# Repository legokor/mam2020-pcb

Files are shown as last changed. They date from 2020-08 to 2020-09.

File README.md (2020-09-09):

## Pinout

### LoRa
| Pin | ESP GPIO |
| --- | --- |
| MISO (2) | 19 |
| MOSI (3) | 23 |
| CLK (4) | 18 |
| CS (5)| 5 |
| RST (6)| 22 |
| DI0 (14) | 21 |

### Motors
| Pin | ESP GPIO |
| --- | --- |
| MOTOR_1_STEP | 27 |
| MOTOR_1_DIR | 14 |
| MOTOR_2_STEP | 12 |
| MOTOR_2_DIR | 17 |
| MOTOR_MODE_0 | 16 |
| MOTOR_MODE_1 | 4 |
| MOTOR_MODE_2 | 0 |

### ADC
| Pin | ESP GPIO |
| --- | --- |
| BATTERY | 34 |

### Servos
| Pin | ESP GPIO |
| --- | --- |
| SERVO_1 | 25 |
| SERVO_2 | 26 |

### Leds
| Pin | ESP GPIO |
| --- | --- |
| LED_1 | 35 |
| LED_2 | 32 |
| LED_3 | 33 |

### Connector

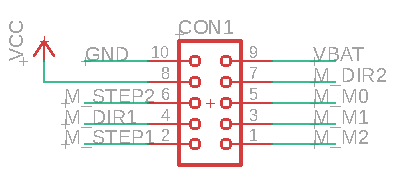
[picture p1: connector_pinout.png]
N|Solid


## Parts list

| Name | Link |
| --- | --- |
| ESP32 | [Pinout](https://www.rpibolt.hu/img/15922/RPI-WS16611_altpic_4/RPI-WS16611_altpic_4.jpg?time=1572739065) |
| DRV8825 | [Datasheet](https://www.pololu.com/product/2133/pictures) |
| HW-613 (DC-DC down) | [Datasheet](https://www.hestore.hu/prod_getfile.php?id=11935) |
| MT3608 (DC-DC up) | [Hestore](https://www.hestore.hu/prod_10038537.html) |
| Stepper motor ( 28BYJ ) | [Datasheet](https://www.hestore.hu/prod_getfile.php?id=8209) |
| RFM95W-868-S2 ( LoRa ) | [Datasheet](https://www.hoperf.com/data/upload/portal/20190301/RFM95_96_97_98W.pdf) |

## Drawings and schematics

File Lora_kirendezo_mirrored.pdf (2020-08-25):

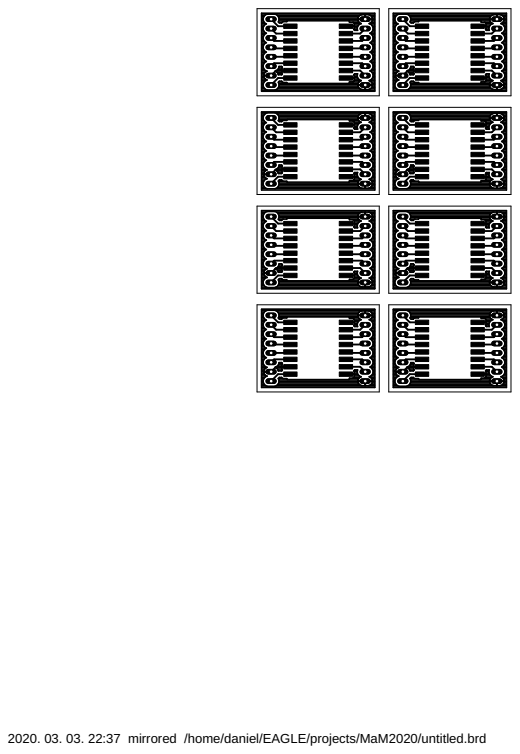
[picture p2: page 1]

2020. 03. 03. 22:37 mirrored /home/daniel/EAGLE/projects/MaM2020/untitled.brd

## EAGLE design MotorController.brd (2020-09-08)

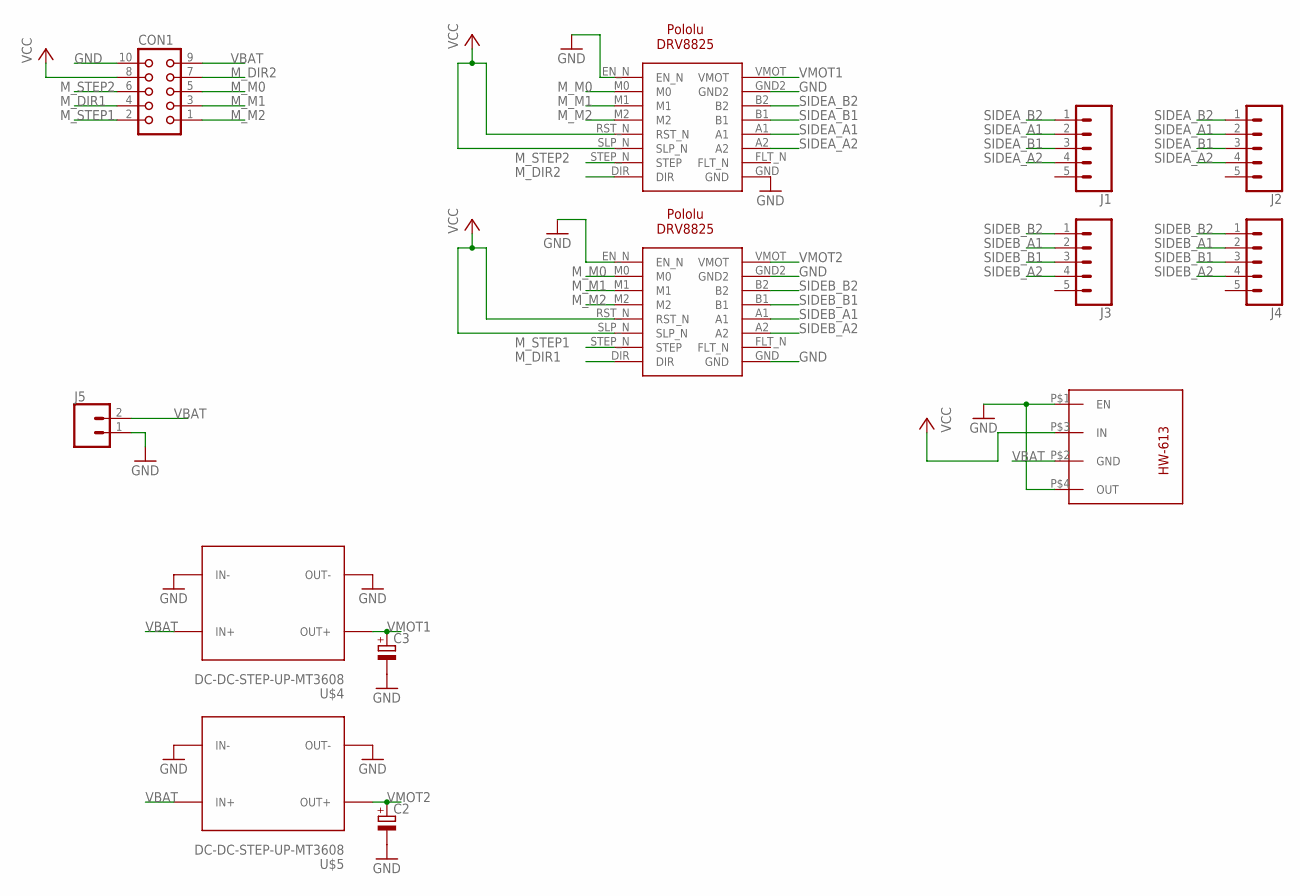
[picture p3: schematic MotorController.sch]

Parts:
C2, C3: CPOL-EUE3.5-10; E3,5-10
CON1: CON10
J1, J2, J3, J4: CONN_05; 1X05
J5: CONN_025MM; SCREWTERMINAL-5MM-2
U$1, U$2: POLOLU-DRV8825
U$4, U$5: DC-DC-STEP-UP-MT3608
U$6: HW-613

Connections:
GND: C2.-, C3.-, CON1.10, J5.1, U$1.EN_N, U$1.GND, U$1.GND2, U$2.EN_N, U$2.GND, U$2.GND2, U$4.IN-, U$4.OUT-, U$5.IN-, U$5.OUT-, U$6.P$1 (EN), U$6.P$4 (OUT)
M_DIR1: CON1.4, U$2.DIR
M_DIR2: CON1.7, U$1.DIR
M_M0: CON1.5, U$1.M0, U$2.M0
M_M1: CON1.3, U$1.M1, U$2.M1
M_M2: CON1.1, U$1.M2, U$2.M2
M_STEP1: CON1.2, U$2.STEP_N (STEP)
M_STEP2: CON1.6, U$1.STEP_N (STEP)
SIDEA_A1: J1.2, J2.2, U$1.A1
SIDEA_A2: J1.4, J2.4, U$1.A2
SIDEA_B1: J1.3, J2.3, U$1.B1
SIDEA_B2: J1.1, J2.1, U$1.B2
SIDEB_A1: J3.2, J4.2, U$2.A1
SIDEB_A2: J3.4, J4.4, U$2.A2
SIDEB_B1: J3.3, J4.3, U$2.B1
SIDEB_B2: J3.1, J4.1, U$2.B2
VBAT: CON1.9, J5.2, U$4.IN+, U$5.IN+, U$6.P$2 (GND)
VCC: CON1.8, U$1.RST_N, U$1.SLP_N, U$2.RST_N, U$2.SLP_N, U$6.P$3 (IN)
VMOT1: C3.+, U$1.VMOT, U$4.OUT+
VMOT2: C2.+, U$2.VMOT, U$5.OUT+

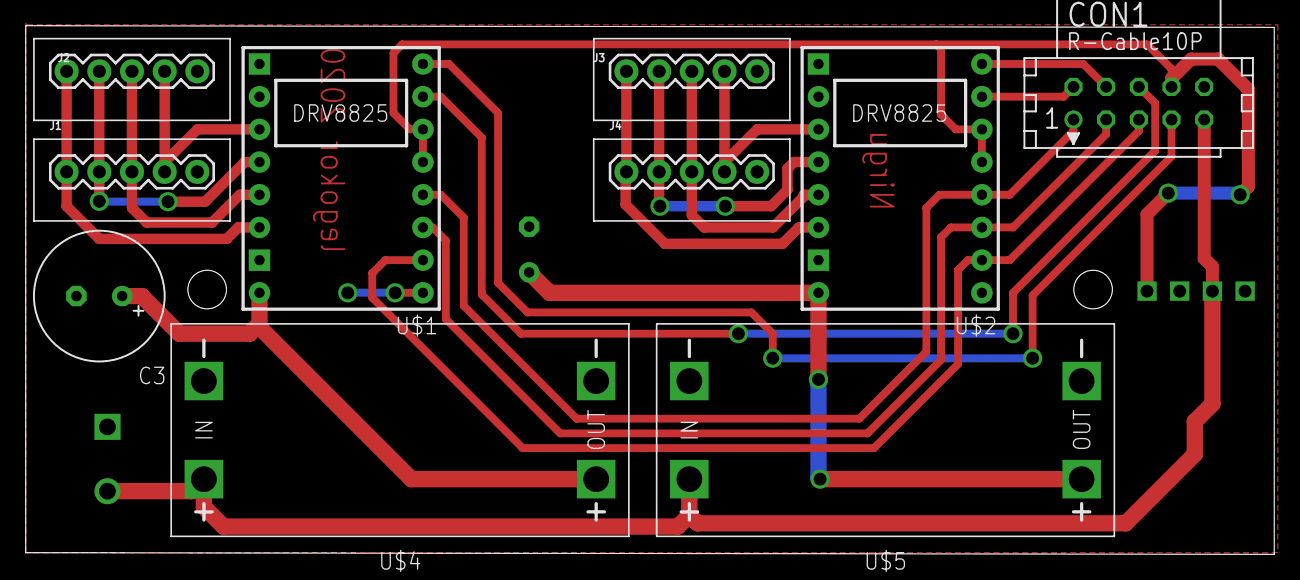
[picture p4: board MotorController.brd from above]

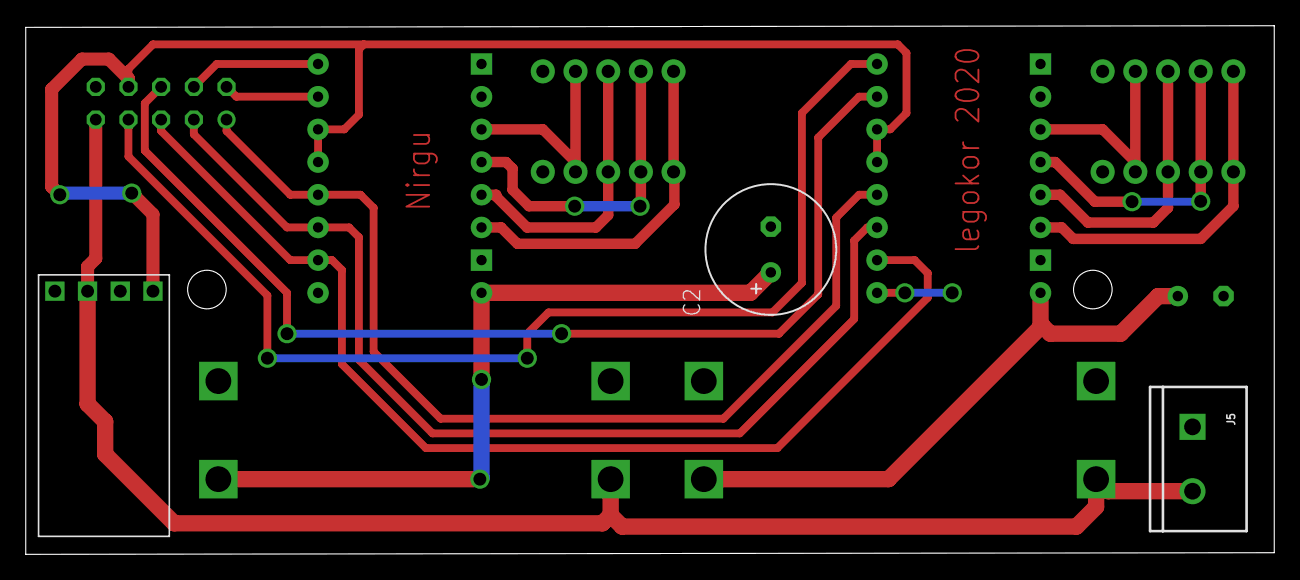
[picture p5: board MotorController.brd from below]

Board: 4 copper layers, 97.0 x 41.1 mm, 13 parts (3 on the bottom side), 20 nets.

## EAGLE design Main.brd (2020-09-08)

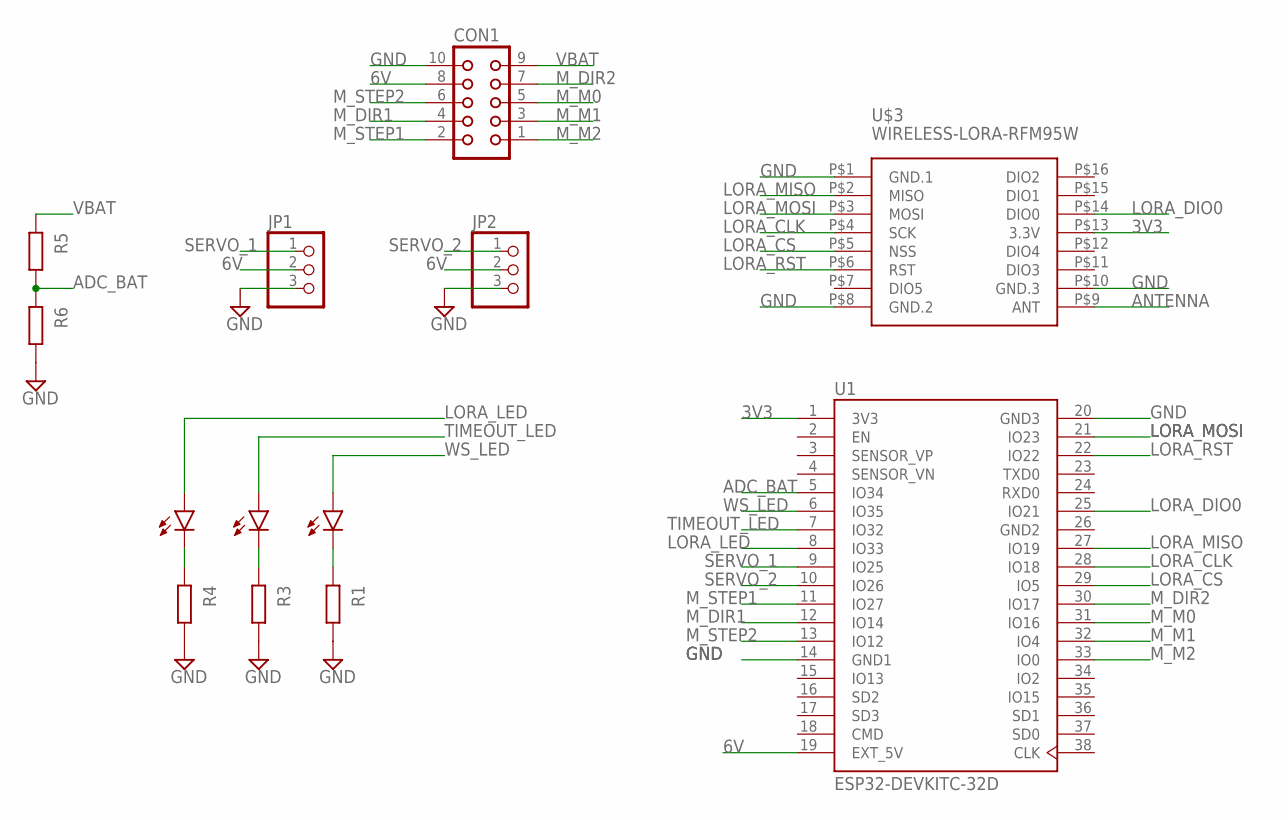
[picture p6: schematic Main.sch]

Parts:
CON1: CON10
JP1, JP2: PINHD-1X3; 1X03
LORA: LED_BLUE; LEDRD254W60D565H860B_B
MV: LED_BLUE; LEDRD254W60D565H860B_B
R1, R3, R4, R5, R6: R_CHIP-0603(1608-METRIC); RESC1608X60
TOUT: LED_BLUE; LEDRD254W60D565H860B_B
U1: ESP32-DEVKITC-32D; MODULE_ESP32-DEVKITC-32D
U$3: WIRELESS-LORA-RFM95W; LORA-BREAKOUT

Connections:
3V3: U1.1 (3V3), U$3.P$13 (3.3V)
6V: CON1.8, JP1.2, JP2.2, U1.19 (EXT_5V)
ADC_BAT: R5.2, R6.1, U1.5 (IO34)
ANTENNA: U$3.P$9 (ANT)
GND: CON1.10, JP1.3, JP2.3, R1.2, R3.2, R4.2, R6.2, U1.14 (GND1), U1.20 (GND3), U$3.P$1 (GND.1), U$3.P$8 (GND.2), U$3.P$10 (GND.3)
GND2: U1.26 (GND2)
LORA_CLK: U1.28 (IO18), U$3.P$4 (SCK)
LORA_CS: U1.29 (IO5), U$3.P$5 (NSS)
LORA_DIO0: U1.25 (IO21), U$3.P$14 (DIO0)
LORA_LED: MV.1 (A), U1.8 (IO33)
LORA_MISO: U1.27 (IO19), U$3.P$2 (MISO)
LORA_MOSI: U1.21 (IO23), U$3.P$3 (MOSI)
LORA_RST: U1.22 (IO22), U$3.P$6 (RST)
M_DIR1: CON1.4, U1.12 (IO14)
M_DIR2: CON1.7, U1.30 (IO17)
M_M0: CON1.5, U1.31 (IO16)
M_M1: CON1.3, U1.32 (IO4)
M_M2: CON1.1, U1.33 (IO0)
M_STEP1: CON1.2, U1.11 (IO27)
M_STEP2: CON1.6, U1.13 (IO12)
unnamed: R3.1, TOUT.2 (C)
unnamed: MV.2 (C), R4.1
unnamed: LORA.2 (C), R1.1
SERVO_1: JP1.1, U1.9 (IO25)
SERVO_2: JP2.1, U1.10 (IO26)
TIMEOUT_LED: TOUT.1 (A), U1.7 (IO32)
VBAT: CON1.9, R5.1
WS_LED: LORA.1 (A), U1.6 (IO35)

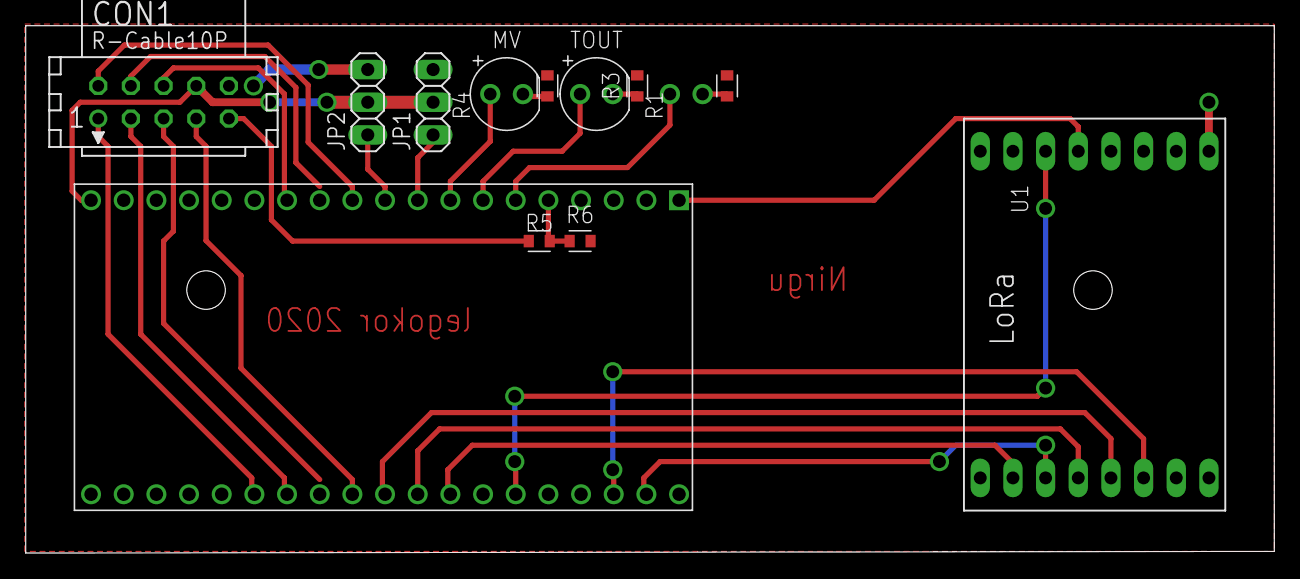
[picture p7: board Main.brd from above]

Board: 2 copper layers, 97.1 x 41.0 mm, 13 parts (1 on the bottom side), 26 nets.

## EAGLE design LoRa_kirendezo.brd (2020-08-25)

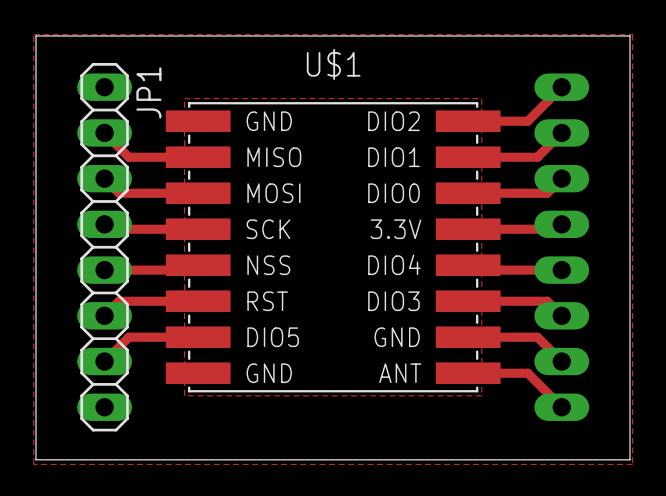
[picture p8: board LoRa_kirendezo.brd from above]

Board: 2 copper layers, 33.0 x 23.5 mm, 3 parts (1 on the bottom side), 14 nets.

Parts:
JP1, JP2: 1X08
U$1: WIRELESS-LORA-RFM95W#SMD

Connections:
GND: JP1.1, JP1.8, JP2.7, U$1.A1, U$1.A8, U$1.B7
unnamed: JP1.2, U$1.A2
unnamed: JP1.3, U$1.A3
unnamed: JP1.4, U$1.A4
unnamed: JP1.5, U$1.A5
unnamed: JP1.6, U$1.A6
unnamed: JP1.7, U$1.A7
unnamed: JP2.8, U$1.B8
unnamed: JP2.6, U$1.B6
unnamed: JP2.5, U$1.B5
unnamed: JP2.4, U$1.B4
unnamed: JP2.3, U$1.B3
unnamed: JP2.2, U$1.B2
unnamed: JP2.1, U$1.B1

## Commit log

2020-09-06 pcb design waiting for inspection
    [DRILEGEND.CFG, MotorController.brd, MotorController.sch]
2020-09-06 esp32 footprint changed
    [Main.brd, Main.sch]
2020-09-07 waiting for review
    [Main.brd, Main.sch]
2020-09-08 fixing points added, overall pcb width modified, cable connections changed
    [MotorController.brd, MotorController.sch]
2020-09-08 via drill size enlarged
    [MotorController.brd]
2020-09-08 panel size fixed, fixing points added
    [Main.brd, Main.sch]
2020-09-08 size dimensions added
    [MotorController.brd, MotorController.sch]
2020-09-08 copyright text mirrored
    [MotorController.brd]
2020-09-09 connector pinout added

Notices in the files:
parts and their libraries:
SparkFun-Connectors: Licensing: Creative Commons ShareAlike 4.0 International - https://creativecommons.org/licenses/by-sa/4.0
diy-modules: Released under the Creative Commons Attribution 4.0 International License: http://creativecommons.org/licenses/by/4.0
